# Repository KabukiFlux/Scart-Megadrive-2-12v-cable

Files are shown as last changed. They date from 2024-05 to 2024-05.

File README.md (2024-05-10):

# Megadrive/Genesis 2 to Scart adapter with 12V

<b align="center">PCB form Megadrive/Genesis 2 RGB minidin to Scart adapter with 12V DCDC boost (4:3 switching)</b>

## Table of contents

- [Why](#why)
- [Description](#description)
- [Schematics](#schematics)
- [Install](#install)
- [Pics and final result](#pics-and-final-result)
- [Premade cables with minidin 9](#premade-cables-with-minidin-9)

## Why?

When we plug a Megadrive 2 console via scart on the "newer" CRT TVs as the minidin provides 5v on the console side the
tv will switch to AV with a 16:9 aspect ratio. We need to deliver between 9v to 12v on the swtiching side to output
directly to AV with 4:3 aspect ratio.

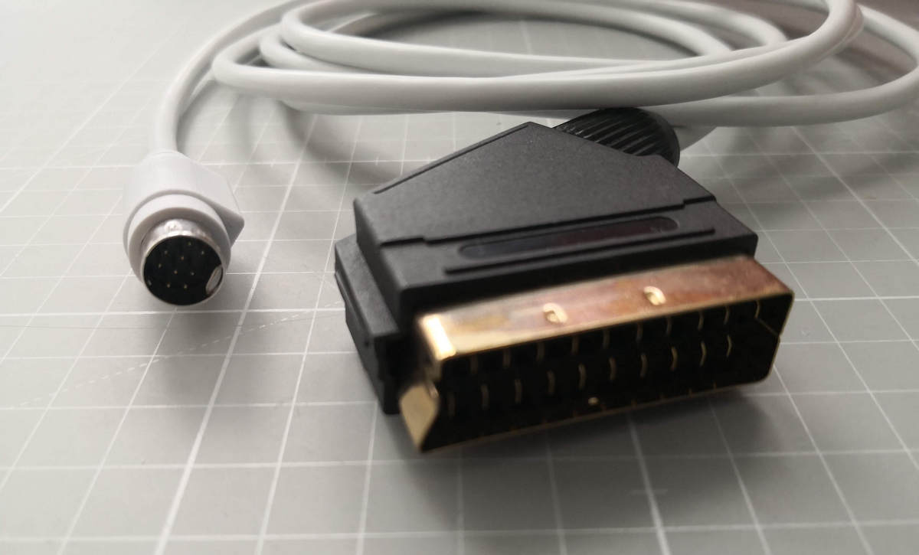
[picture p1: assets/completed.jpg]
Completed Megadrive 2 cable


## Description

This is intended to be a PCB using the default Megadrive/Genesis 2 RGB cable schematic but adding the 12v DC-DC switching boost
on the scart side from the 5v supplied by the MD2.

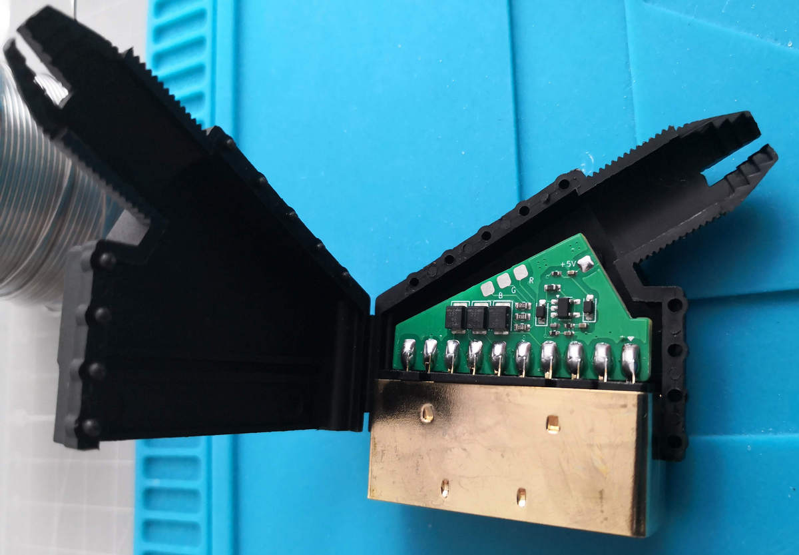
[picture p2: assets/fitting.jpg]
Fitting


This board intends to provide a standard Sega Megadrive 2 RGB cable (Sega Genesis).

In the BOM directory there's an interactive BOM with all the required components.

In the gerbers directory we have the gerbers to manufacture the boards.

In the KiCAD folder we can find the KiCAD project itself.

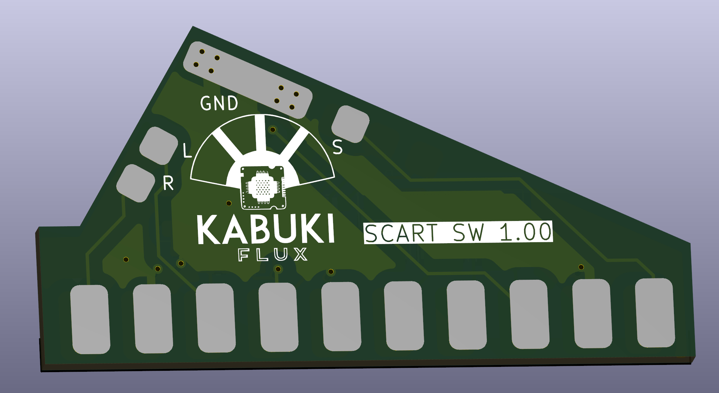
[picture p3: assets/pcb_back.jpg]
Render back


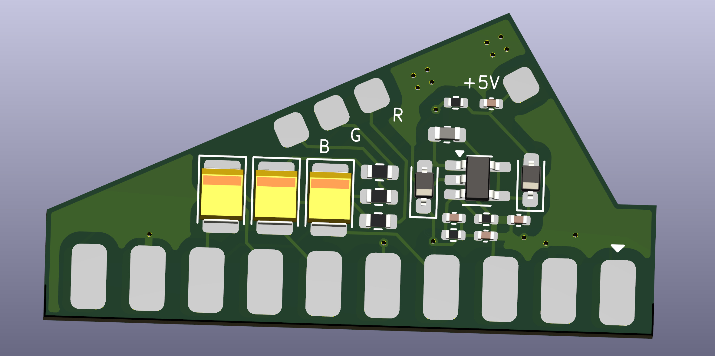
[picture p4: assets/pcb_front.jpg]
Render front


## Schematics

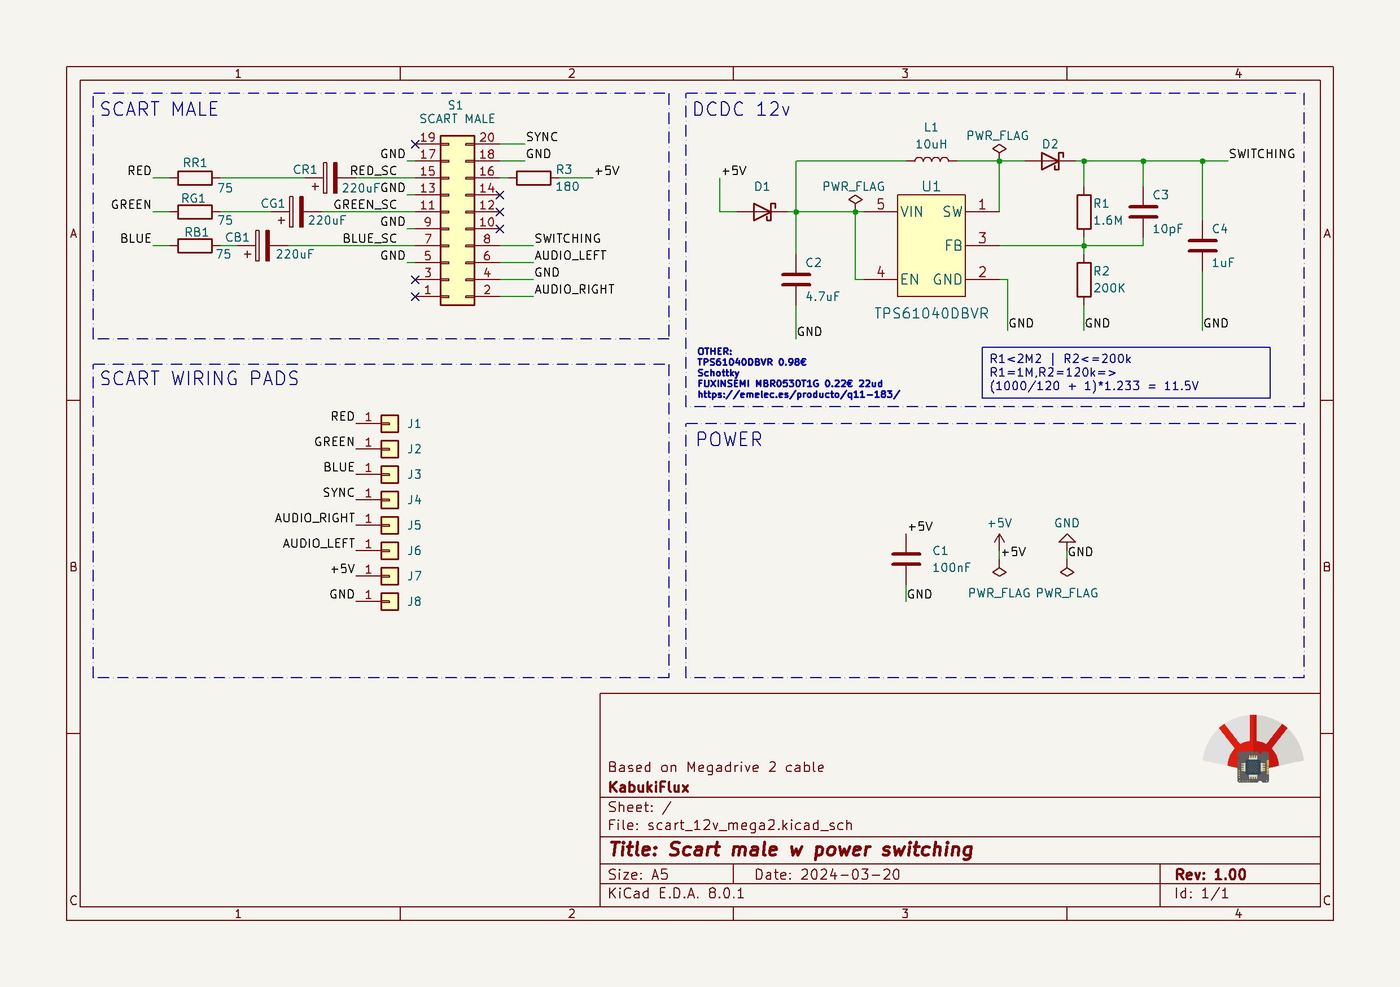
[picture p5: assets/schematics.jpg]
Schematics


You can find a copy on PDF on the root of the repository.

## Install

1- Send to manufacture the GERBER board to JLCPCB or other PCB manufacturer.

2- Get the components required, you can see here the Bill Of Materials [BOM](ibom.html)

3- Solder the wire to each of the pads and to the scart male.

4- Remember to solder the shield of the scart to the GND as well to avoid noise issues.

### Pics and final result

At this stage you should have something like this:

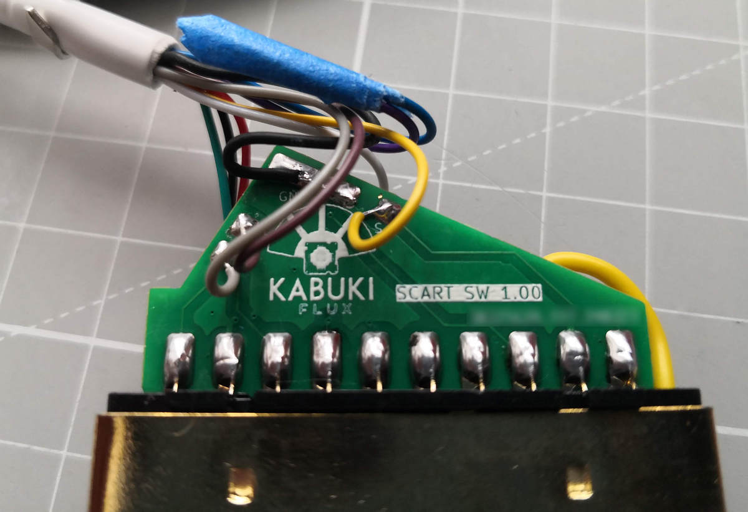
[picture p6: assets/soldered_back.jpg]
Soldered back


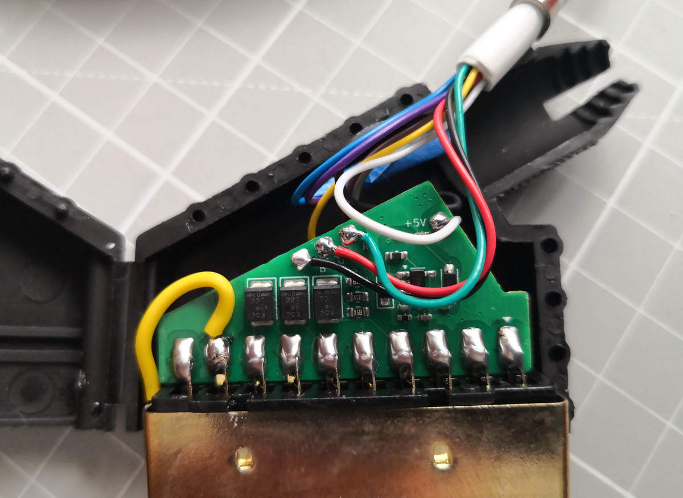
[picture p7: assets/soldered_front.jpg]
Soldered front


## Premade cables with minidin 9

Of course you can always try to solder the minidin 9 connectors from Aliexpress, good luck with that!

(You will need good flux and scratch the surface - some of them are almost imposible)

But my recommendation is to buy these ones:

1- RS 75ohm cable with shield: [RS Spain link code 724-1150](https://es.rs-online.com/web/p/cables-din/7241150)

2- Minidin 9 male to male cable: [Aliexpress 3m male to male with shield](https://es.aliexpress.com/item/1005006201886253.html)

I'm not responsible
============
And yes, read below, no responsibility taken on bad use.

DISCLAIMER (See Licensing)
==========================
See LICENSE for more information.

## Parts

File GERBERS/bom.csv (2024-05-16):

Designator | Footprint | Quantity | Value | LCSC Part #
C1 | 0402 | 1 | 100nF | C1525
C2 | 0402 | 1 | 4.7uF | C23733
C3 | 0402 | 1 | 10pF | C32949
C4 | 0402 | 1 | 1uF | C52923
CB1, CG1, CR1 | CP_EIA-3528-21_Kemet-B_Pad1.50x2.35mm_HandSolder | 3 | 220uF | C254404
D1, D2 | D_SOD-323_HandSoldering | 2 | D_Schottky | C191023
L1 | 0603 | 1 | 10uH | C2047264
R1 | 0402 | 1 | 1.6M | C327245
R2 | 0402 | 1 | 200K | C25764
R3 | 0402 | 1 | 180 | C38941
RB1, RG1, RR1 | 0603 | 3 | 75 | C4275
U1 | SOT-23-5_HandSoldering | 1 | TPS61040DBVR | C7722

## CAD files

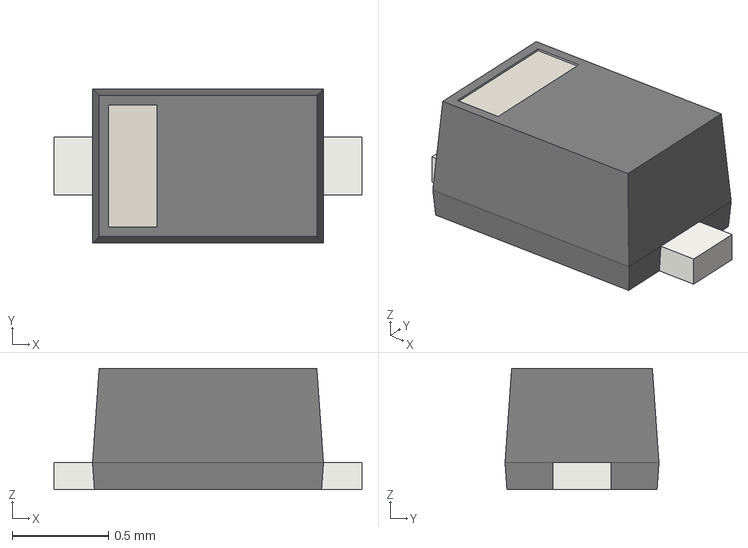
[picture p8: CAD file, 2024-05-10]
KiCAD/3D/D_SOD-523.step
1.60 x 0.8 x 0.63 mm

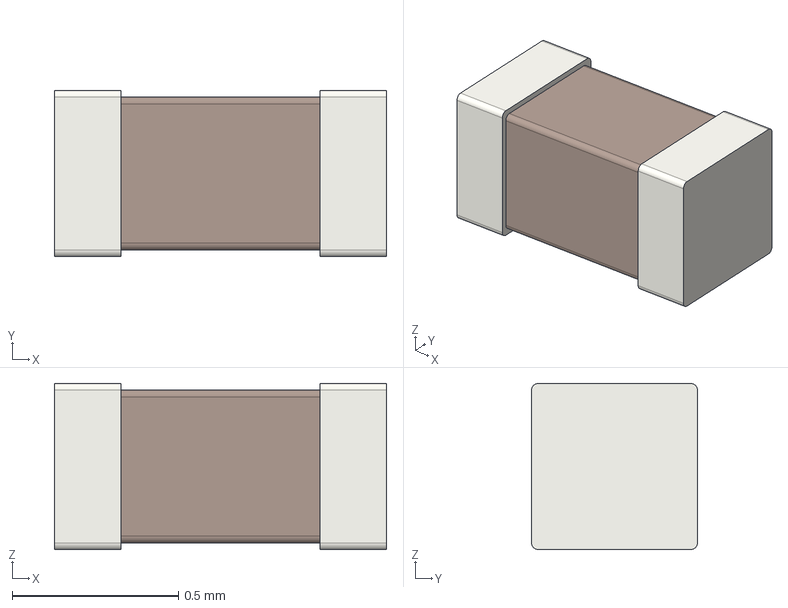
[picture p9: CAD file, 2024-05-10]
KiCAD/3D/C_0402_1005Metric.step
1.00 x 0.5 x 0.5 mm

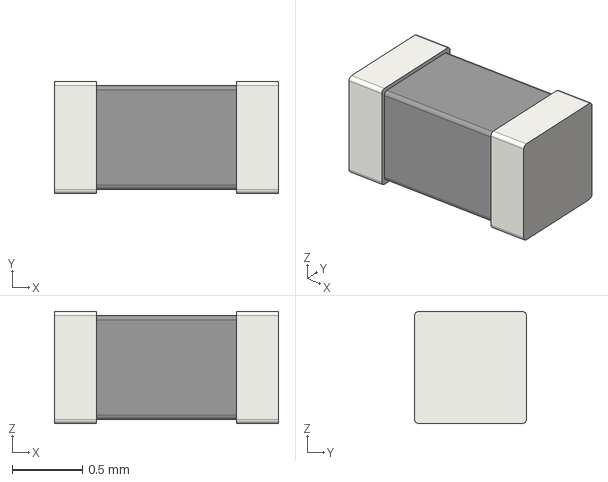
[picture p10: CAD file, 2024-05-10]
KiCAD/3D/L_0603_1608Metric.step
1.60 x 0.8 x 0.8 mm

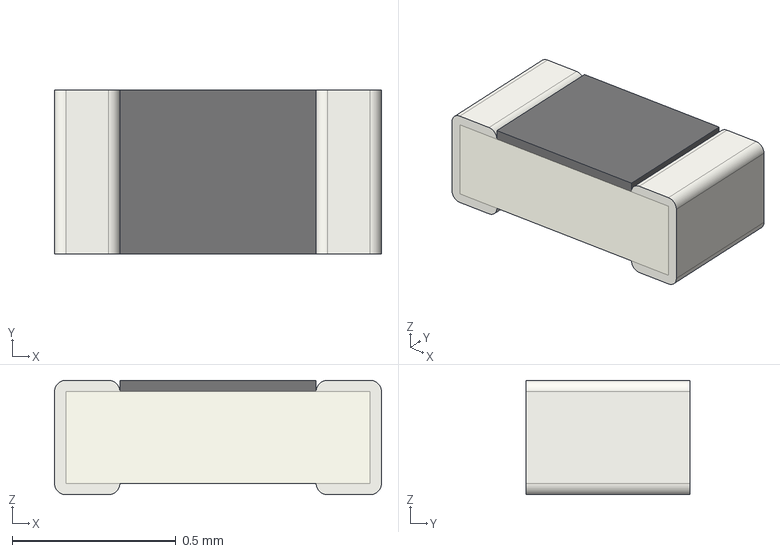
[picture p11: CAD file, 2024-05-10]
KiCAD/3D/R_0402_1005Metric.step
1.00 x 0.5 x 0.35 mm

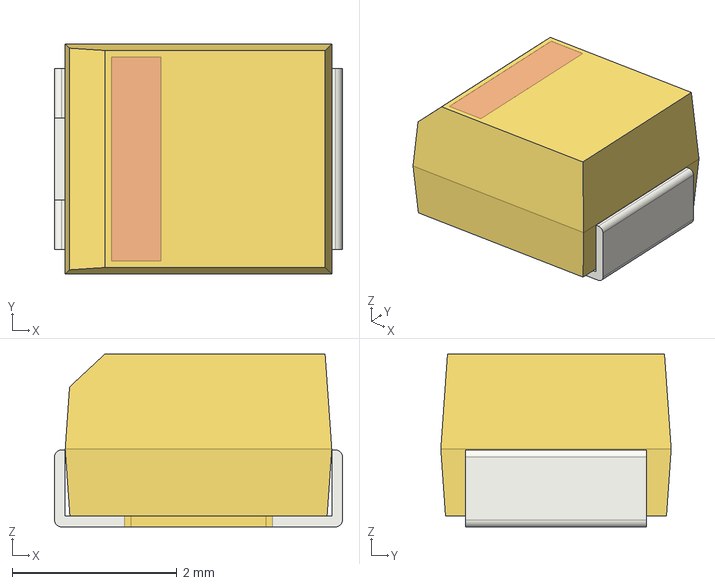
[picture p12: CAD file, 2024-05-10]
KiCAD/3D/CP_EIA-3528-21_Kemet-B.step
3.50 x 2.80 x 2.10 mm

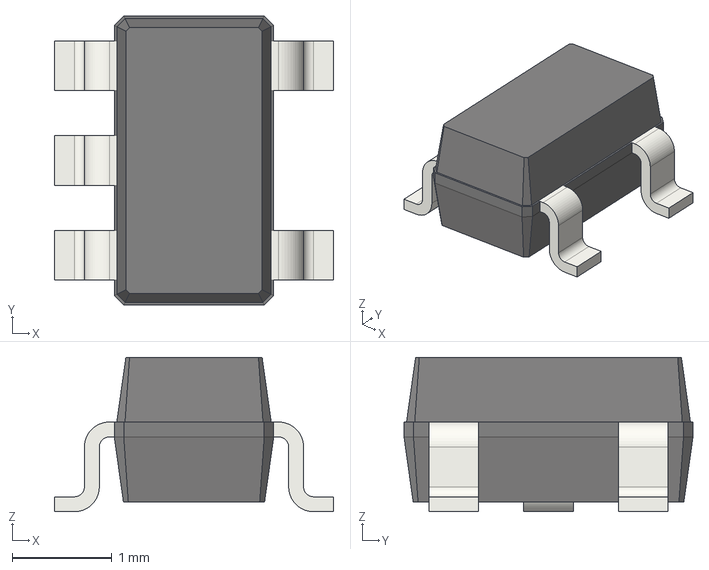
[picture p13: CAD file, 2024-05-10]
KiCAD/3D/SOT-23-5.step
2.80 x 2.90 x 1.55 mm

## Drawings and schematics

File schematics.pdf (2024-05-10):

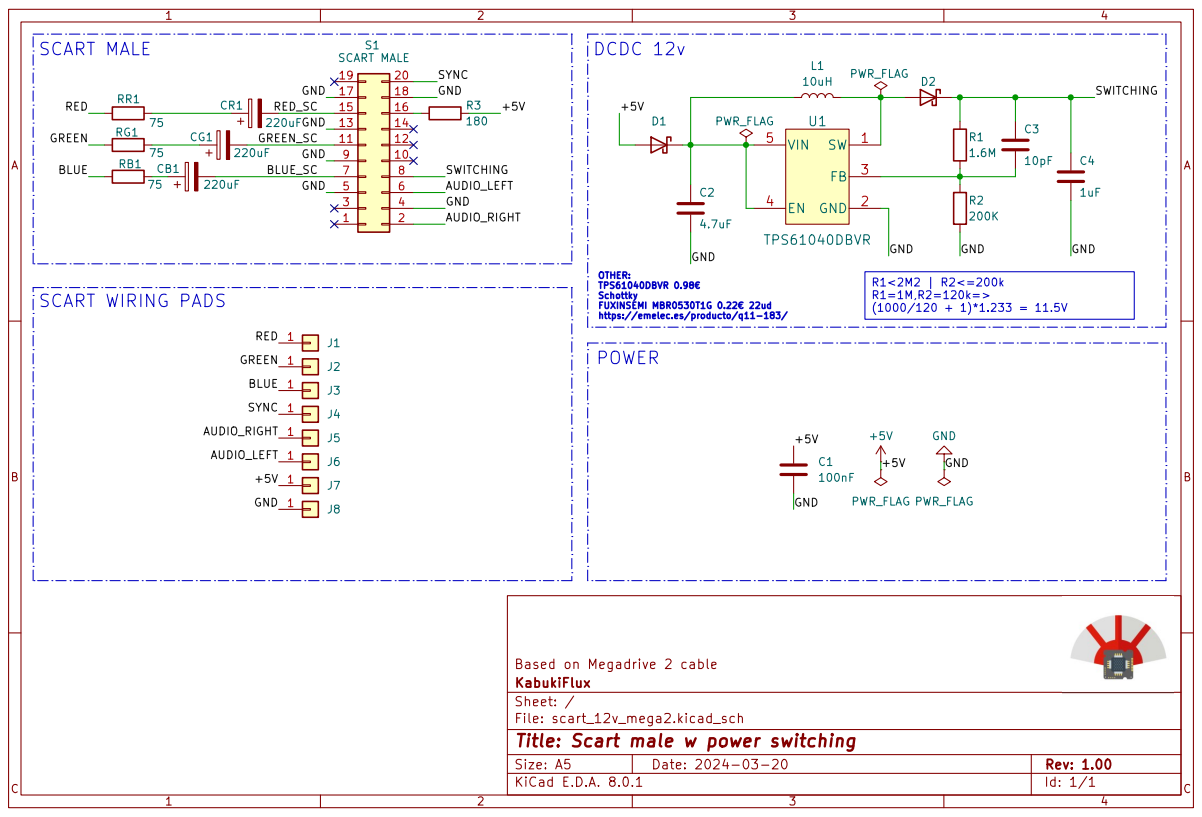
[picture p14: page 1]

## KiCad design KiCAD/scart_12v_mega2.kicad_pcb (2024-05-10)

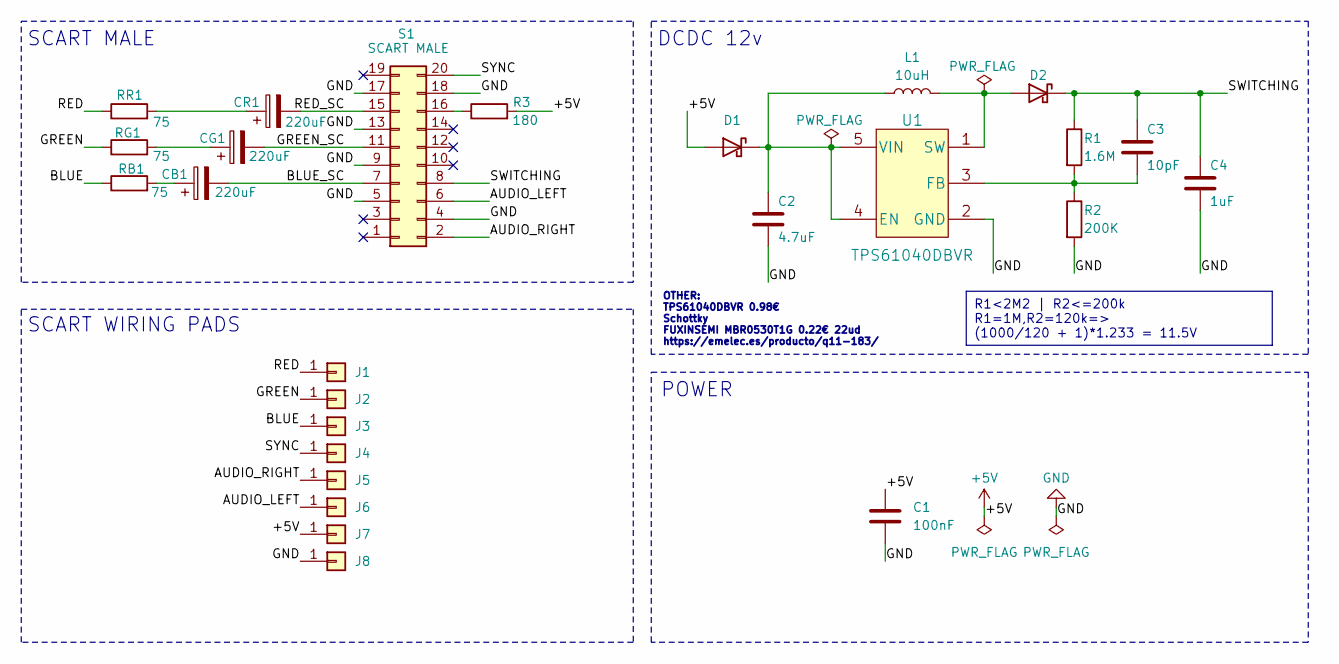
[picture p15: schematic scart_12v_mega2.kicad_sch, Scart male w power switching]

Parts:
C1: 100nF; C_0402_1005Metric; Manufacturer_Part_Number CL05B104KO5NNNC; LCSC Part C1525
C2: 4.7uF; C_0402_1005Metric; Manufacturer_Part_Number CL05A475MP5NRNC; LCSC Part C23733
C3: 10pF; C_0402_1005Metric; Manufacturer_Part_Number CL05C100JB5NNNC; LCSC Part C32949
C4: 1uF; C_0402_1005Metric; Manufacturer_Part_Number CL05A105KA5NQNC; LCSC Part C52923
CB1: 220uF; CP_EIA-3528-21_Kemet-B_Pad1.50x2.35mm_HandSolder; Manufacturer_Part_Number T520B227M006ATE045; LCSC Part C254404
CG1: 220uF; CP_EIA-3528-21_Kemet-B_Pad1.50x2.35mm_HandSolder; Manufacturer_Part_Number T520B227M006ATE045; LCSC Part C254404
CR1: 220uF; CP_EIA-3528-21_Kemet-B_Pad1.50x2.35mm_HandSolder; Manufacturer_Part_Number T520B227M006ATE045; LCSC Part C254404
D1, D2: D_Schottky; D_SOD-323_HandSoldering; Manufacturer_Part_Number 1N5819WS; LCSC Part C191023
J1, J2, J3, J4, J5, J6, J7: Conn_01x01; PAD2x2mm
J8: Conn_01x01; PAD2x8mm
L1: 10uH; L_0603_1608Metric; Manufacturer_Part_Number MLZ1608M100WTD25; LCSC Part C2047264
R1: 1.6M; R_0402_1005Metric; Manufacturer_Part_Number RC0402FR-071M6L; LCSC Part C327245
R2: 200K; R_0402_1005Metric; Manufacturer_Part_Number 0402WGF2003TCE; LCSC Part C25764
R3: 180; R_0402_1005Metric; Manufacturer_Part_Number 0402WGF1800TCE; LCSC Part C38941
RB1: 75; R_0603_1608Metric; Manufacturer_Part_Number 0603WAF750JT5E; LCSC Part C4275
RG1: 75; R_0603_1608Metric; Manufacturer_Part_Number 0603WAF750JT5E; LCSC Part C4275
RR1: 75; R_0603_1608Metric; Manufacturer_Part_Number 0603WAF750JT5E; LCSC Part C4275
S1: SCART MALE; SCART
U1: TPS61040DBVR; SOT-23-5_HandSoldering; Manufacturer_Part_Number TPS61040DBVR; LCSC Part C7722

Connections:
+5V: C1.1, D1.2 (A), J7.1, R3.2
/AUDIO_LEFT: J6.1, S1.6
/AUDIO_RIGHT: J5.1, S1.2
/BLUE: J3.1, RB1.1
/BLUE_SC: CB1.2, S1.7
/GREEN: J2.1, RG1.1
/GREEN_SC: CG1.2, S1.11
/RED: J1.1, RR1.1
/RED_SC: CR1.2, S1.15
/SWITCHING: C3.1, C4.1, D2.1 (K), R1.1, S1.8
/SYNC: J4.1, S1.20
GND: C1.2, C2.2, C4.2, J8.1, R2.2, S1.4, S1.5, S1.9, S1.13, S1.17, S1.18, U1.2 (GND)
unnamed: CB1.1, RB1.2
unnamed: CG1.1, RG1.2
unnamed: CR1.1, RR1.2
unnamed: C2.1, D1.1 (K), L1.1, U1.4 (EN), U1.5 (VIN)
unnamed: D2.2 (A), L1.2, U1.1 (SW)
unnamed: R3.1, S1.16
unnamed: C3.2, R1.2, R2.1, U1.3 (FB)

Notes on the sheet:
R1<2M2 | R2<=200k R1=1M,R2=120k=> (1000/120 + 1)*1.233 = 11.5V
OTHER: TPS61040DBVR 0.98€ Schottky FUXINSEMI MBR0530T1G 0.22€ 22ud https://emelec.es/producto/q11-183/
SCART WIRING PADS
POWER
SCART MALE
DCDC 12v

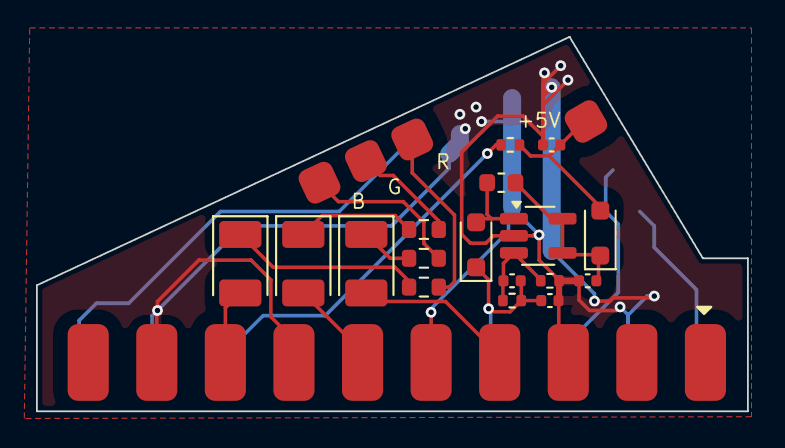
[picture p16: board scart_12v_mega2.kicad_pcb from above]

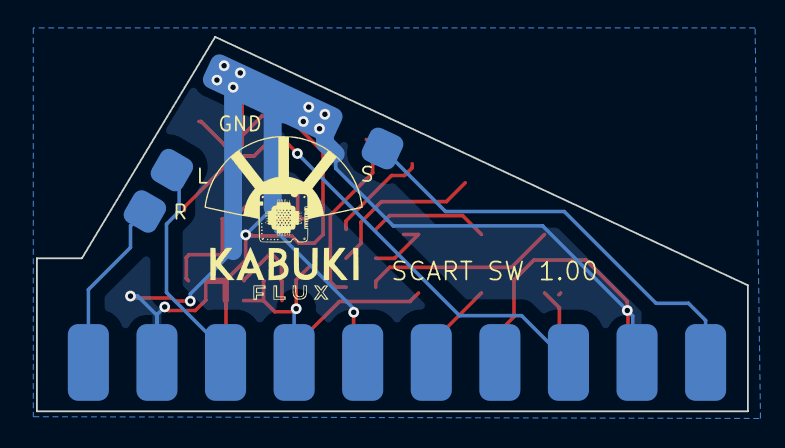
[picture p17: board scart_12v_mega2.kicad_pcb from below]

Board: 2 copper layers, 39.5 x 20.8 mm, 27 parts (5 on the bottom side), 19 nets.

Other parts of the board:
G1: LOGO; LogoKabuki_10mm

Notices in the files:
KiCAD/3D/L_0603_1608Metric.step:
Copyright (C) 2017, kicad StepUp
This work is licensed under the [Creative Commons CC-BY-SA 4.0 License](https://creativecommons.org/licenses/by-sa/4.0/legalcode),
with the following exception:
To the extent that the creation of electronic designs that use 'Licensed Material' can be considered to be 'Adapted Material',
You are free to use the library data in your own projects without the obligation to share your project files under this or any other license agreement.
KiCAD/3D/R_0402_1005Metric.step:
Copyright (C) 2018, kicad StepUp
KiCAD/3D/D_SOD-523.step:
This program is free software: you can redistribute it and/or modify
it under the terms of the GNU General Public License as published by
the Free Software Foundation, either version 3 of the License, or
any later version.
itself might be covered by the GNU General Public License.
